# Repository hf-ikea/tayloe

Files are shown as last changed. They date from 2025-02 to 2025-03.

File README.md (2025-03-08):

### tayloe downmixer
This is a simple I/Q downmixer intended for use with a soundcard for digitization, with one (very poor) revision created in a weekend, after I discovered the existence of Tayloe detectors online. Created under the influence of music (sumic). Iterations have occured, with the recommended version being the latest commit to this repo. As of writing, however, the design has not been tested in real world (but shall eventually be). The current (and likely forever) design uses a FT232H communicating over I2C to a Si5351A that is then used in a divide-by-four to create the I/Q paired LO, fed into the multiplexer. On the front end is a simple elliptical LPF with a ~30MHz rolloff, and a 1.8V bias circuit. The sample capacitors are of value 0.068uF, which are on the input of an ADA4084 operational amplifier. This is connected through bypass capacitors to the 3.5mm audio jack. For simplicity, a single rail supply is used for the operational amplifier, as the bias on the input should maintain a proper swing.\
"Inspired" by the classic "A Software Defined Radio for the Masses" Series, published in QEX (and available in this repo).\
Hardware is licensed under CERN Open Hardware Licence Version 2 - Strongly Reciprocal (LICENSE.txt)

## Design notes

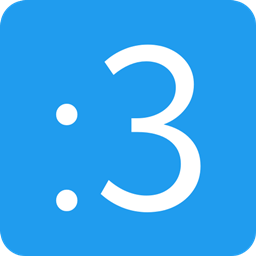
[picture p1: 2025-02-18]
Datasheets/important_data.png

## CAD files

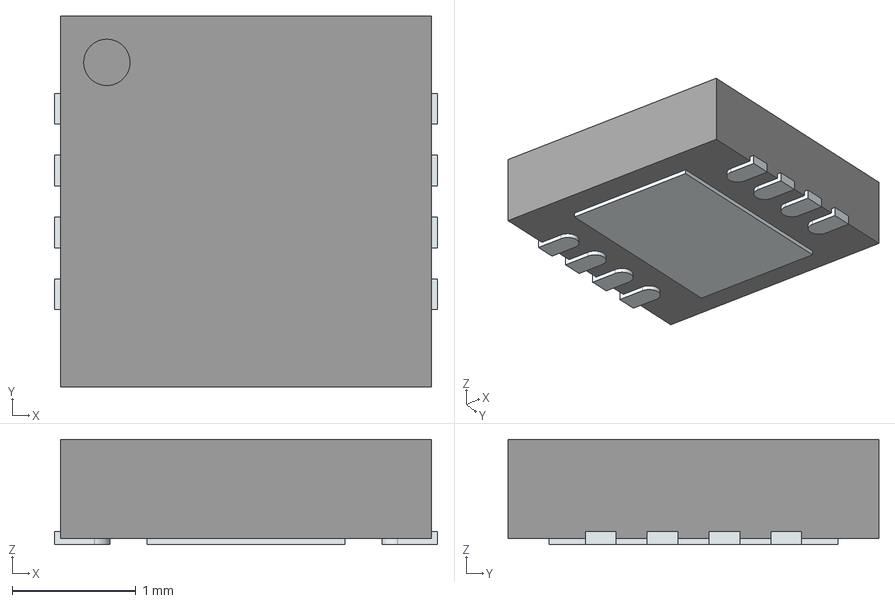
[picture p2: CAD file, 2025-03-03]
3DModels/ADA4084-2ACPZ-R7.stp
3.10 x 3.00 x 0.85 mm
ThermalPin
PinsArrayLR

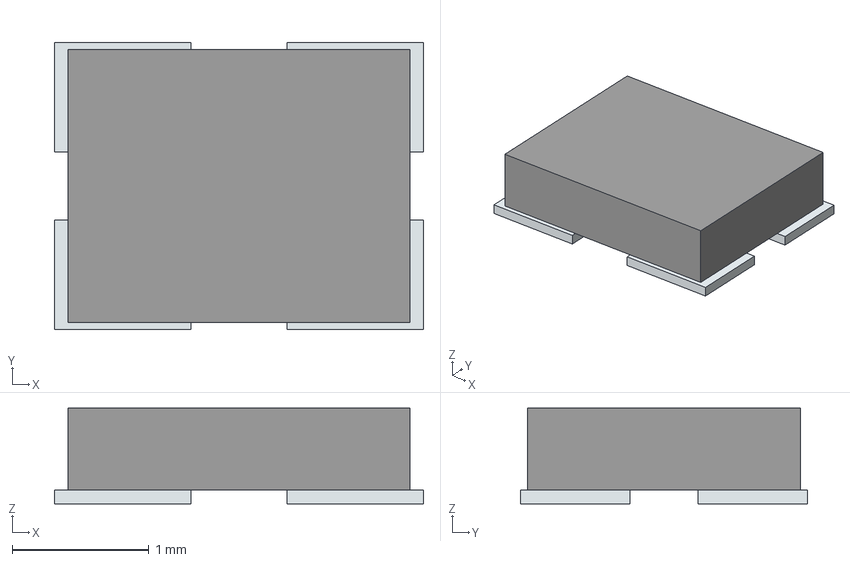
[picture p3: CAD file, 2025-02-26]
3DModels/ECS-120-8-36-CKM-TR3.stp
2.70 x 2.10 x 0.7 mm
Pins

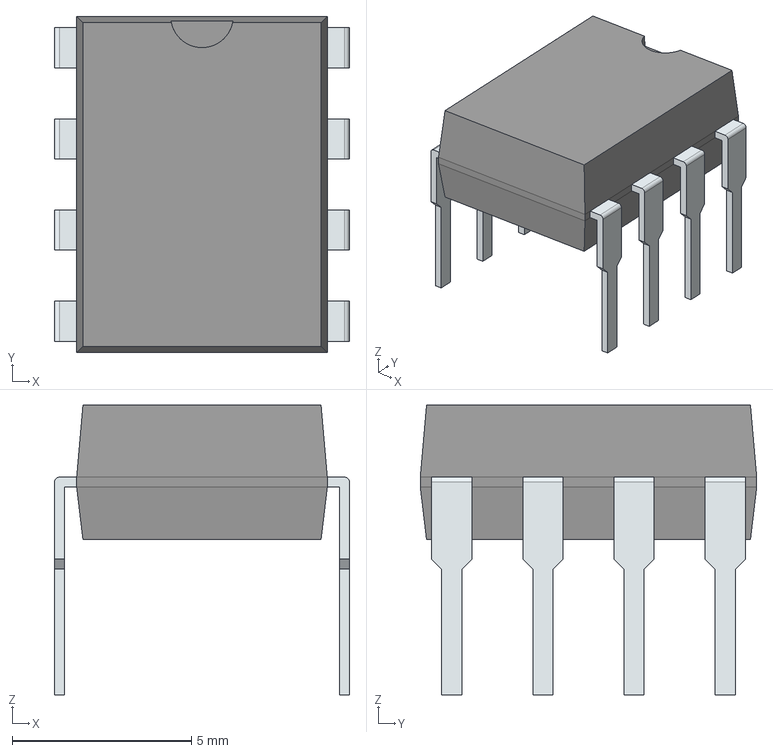
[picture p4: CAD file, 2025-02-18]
3DModels/MAX1044CPA+.stp
8.22 x 9.38 x 8.07 mm
PinsArrayLR

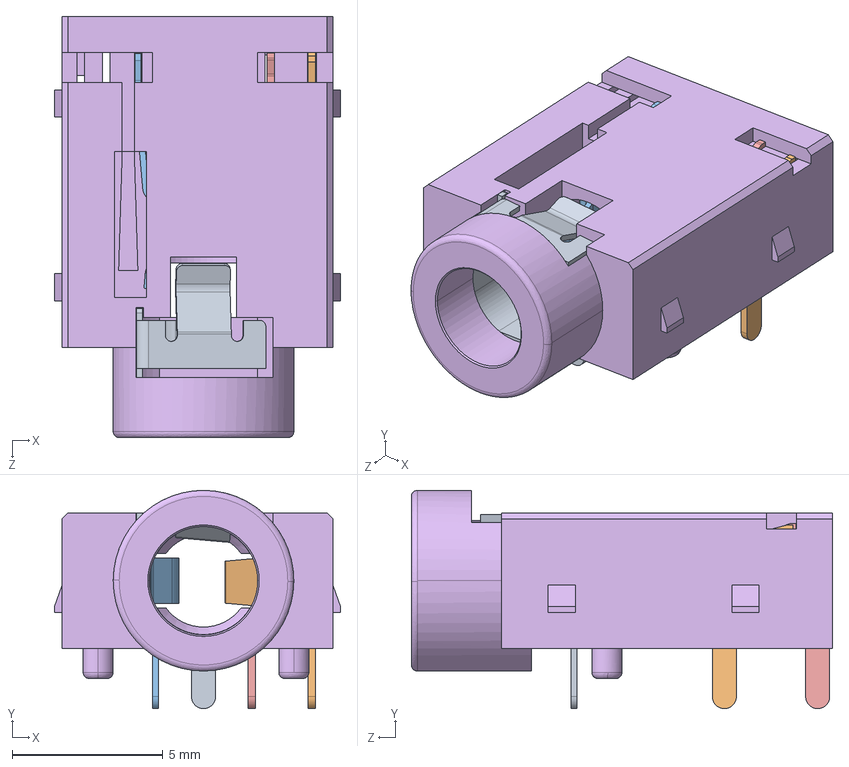
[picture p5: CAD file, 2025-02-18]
3DModels/Same_Sky_SJ3-35063B.step
9.50 x 7.25 x 14.0 mm

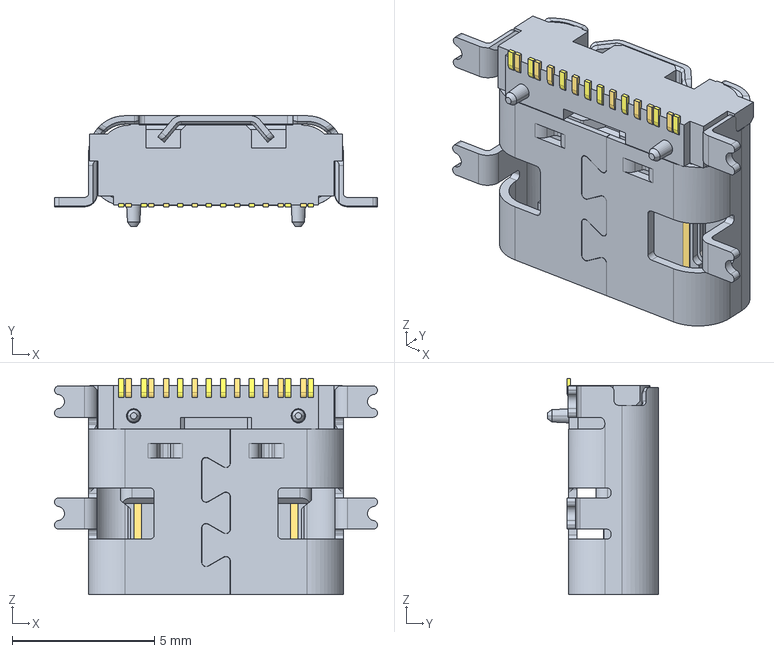
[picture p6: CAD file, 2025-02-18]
3DModels/GSB1C41110SSHR.stp
11.3 x 3.89 x 7.60 mm

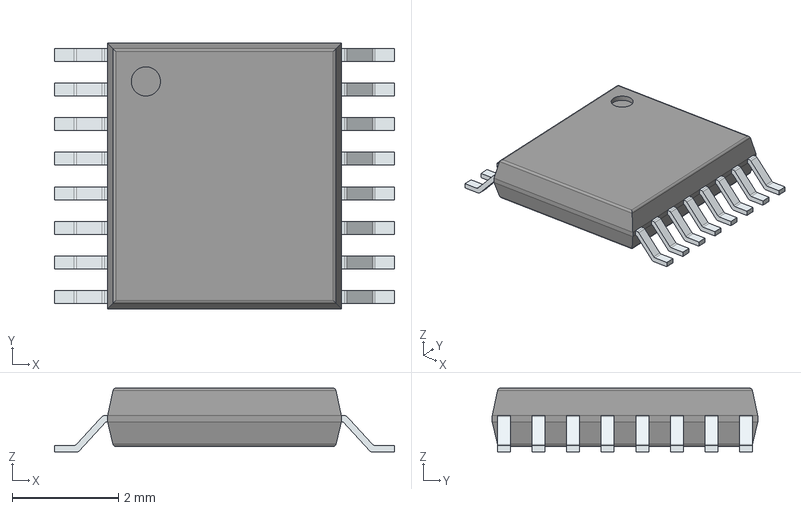
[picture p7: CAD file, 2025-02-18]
3DModels/PI3B3253LEX.stp
6.40 x 5.00 x 1.20 mm
PinsArrayLR

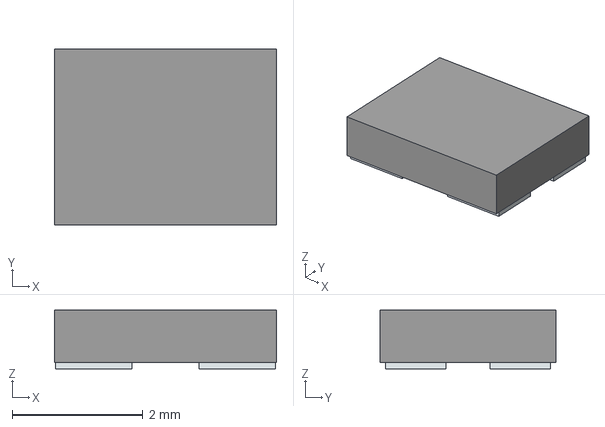
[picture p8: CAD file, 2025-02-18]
3DModels/830105420809.stp
3.40 x 2.70 x 0.9 mm
Pins

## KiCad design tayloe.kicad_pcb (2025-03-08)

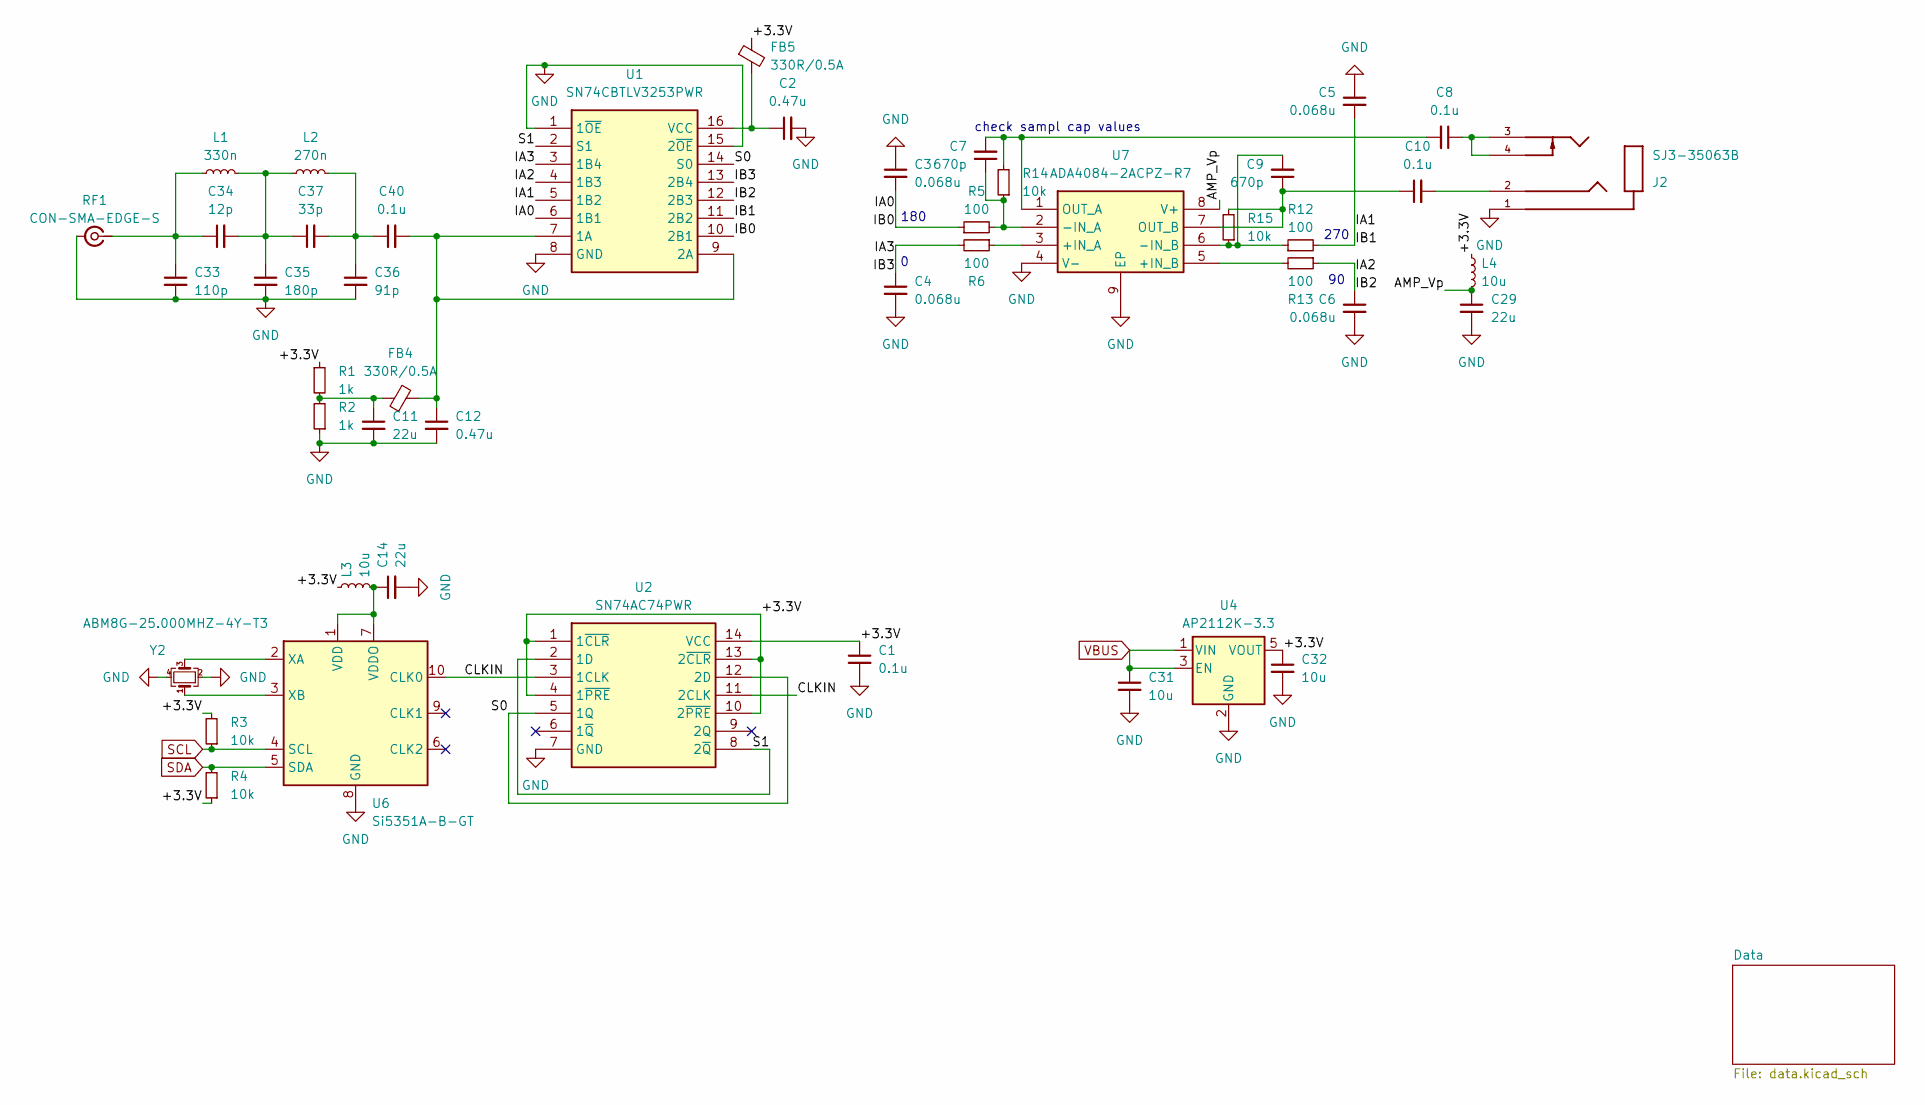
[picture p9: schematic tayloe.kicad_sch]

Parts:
C1, C8, C10, C40: 0.1u; C_0603_1608Metric
C2, C12: 0.47u; C_0603_1608Metric
C3, C4, C5, C6: 0.068u; C_0603_1608Metric; Mouser Part 603-CC603JRX7R8BB683
C7, C9: 670p; C_0603_1608Metric; Mouser Part 603-CC603JRX7R8BB683
C11, C14, C29: 22u; C_0603_1608Metric
C31, C32: 10u; C_0603_1608Metric
C33: 110p; C_0603_1608Metric
C34: 12p; C_0603_1608Metric
C35: 180p; C_0603_1608Metric
C36: 91p; C_0603_1608Metric
C37: 33p; C_0603_1608Metric
FB4, FB5: 330R/0.5A; L_0603_1608Metric; Mouser Part 81-BLM18HK331SN1
J2: SJ3-35063B; SAMESKY_SJ3-35063B; PARTREV 1.0
L1: 330n; L_0603_1608Metric
L2: 270n; L_0603_1608Metric
L3, L4: 10u; L_0603_1608Metric
R1, R2: 1k; R_0603_1608Metric
R3, R4, R14, R15: 10k; R_0603_1608Metric
R5, R6, R12, R13: 100; R_0603_1608Metric
RF1: CON-SMA-EDGE-S; SMA_Amphenol_132289_EdgeMount
U1: SN74CBTLV3253PWR; TSSOP-16_4.4x5mm_P0.65mm; Mouser Part 595-SN74CBTLV3253PWR
U2: SN74AC74PWR; TSSOP-14_4.4x5mm_P0.65mm; Mouser Part Number 595-SN74AC74PWR
U4: AP2112K-3.3; SOT-23-5
U6: Si5351A-B-GT; MSOP-10_3x3mm_P0.5mm
U7: ADA4084-2ACPZ-R7; LFCSP-8-1EP_3x3mm_P0.5mm_EP1.6x2.34mm_ThermalVias; Mouser Part 584-ADA4084-2ACPZ-R7
Y2: ABM8G-25.000MHZ-4Y-T3; Crystal_SMD_Abracon_ABM8G-4Pin_3.2x2.5mm

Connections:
/+3.3V: C1.1, C32.1, FB5.1, L3.1, L4.1, R1.1, R3.2, R4.1, U2.1 (1~CLR), U2.4 (1~PRE), U2.10 (2~PRE), U2.13 (2~CLR), U2.14 (VCC), U4.5 (VOUT)
/AMP_Vp: C29.1, L4.2, U7.8 (V+)
/CLKIN: U2.3 (1CLK), U2.11 (2CLK), U6.10 (CLK0)
/IA0: C3.2, R5.1, U1.6 (1B1), U1.10 (2B1)
/IA1: C5.2, R12.2, U1.5 (1B2), U1.11 (2B2)
/IA2: C6.1, R13.1, U1.4 (1B3), U1.12 (2B3)
/IA3: C4.1, R6.2, U1.3 (1B4), U1.13 (2B4)
/S0: U1.14 (S0), U2.5 (1Q), U2.12 (2D)
/S1: U1.2 (S1), U2.2 (1D), U2.8 (2~Q)
GND: C1.2, C2.2, C3.1, C4.2, C5.1, C6.2, C11.2, C12.2, C14.2, C29.2, C31.2, C32.2, C33.2, C35.2, C36.2, J2.1, R2.1, RF1.2 (Ext), U1.1 (1~OE), U1.8 (GND), U1.15 (2~OE), U2.7 (GND), U4.2 (GND), U6.8 (GND), U7.4 (V-), U7.9 (EP), Y2.2, Y2.4; also elsewhere on the board
unnamed: C8.1, J2.3, J2.4
unnamed: C10.2, J2.2
unnamed: C11.1, FB4.1, R1.2, R2.2
unnamed: C34.2, C35.1, C37.1, L1.2, L2.1
unnamed: C36.1, C37.2, C40.1, L2.2
unnamed: C33.1, C34.1, L1.1, RF1.1 (In)
unnamed: C12.1, C40.2, FB4.2, U1.7 (1A), U1.9 (2A)
unnamed: C2.1, FB5.2, U1.16 (VCC)
unnamed: C14.1, L3.2, U6.1 (VDD), U6.7 (VDDO)
unnamed: U6.2 (XA), Y2.3
unnamed: U6.3 (XB), Y2.1
unnamed: R6.1, U7.3 (+IN_A)
unnamed: R13.2, U7.5 (+IN_B)
unnamed: C7.1, R5.2, R14.1, U7.2 (-IN_A)
unnamed: C9.2, R12.1, R15.1, U7.6 (-IN_B)
unnamed: C7.2, C8.2, R14.2, U7.1 (OUT_A)
unnamed: C9.1, C10.1, R15.2, U7.7 (OUT_B)
SCL: R3.1, U6.4 (SCL); also elsewhere on the board
SDA: R4.2, U6.5 (SDA); also elsewhere on the board
VBUS: C31.1, U4.1 (VIN), U4.3 (EN); also elsewhere on the board

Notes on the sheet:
check sampl cap values
270
180

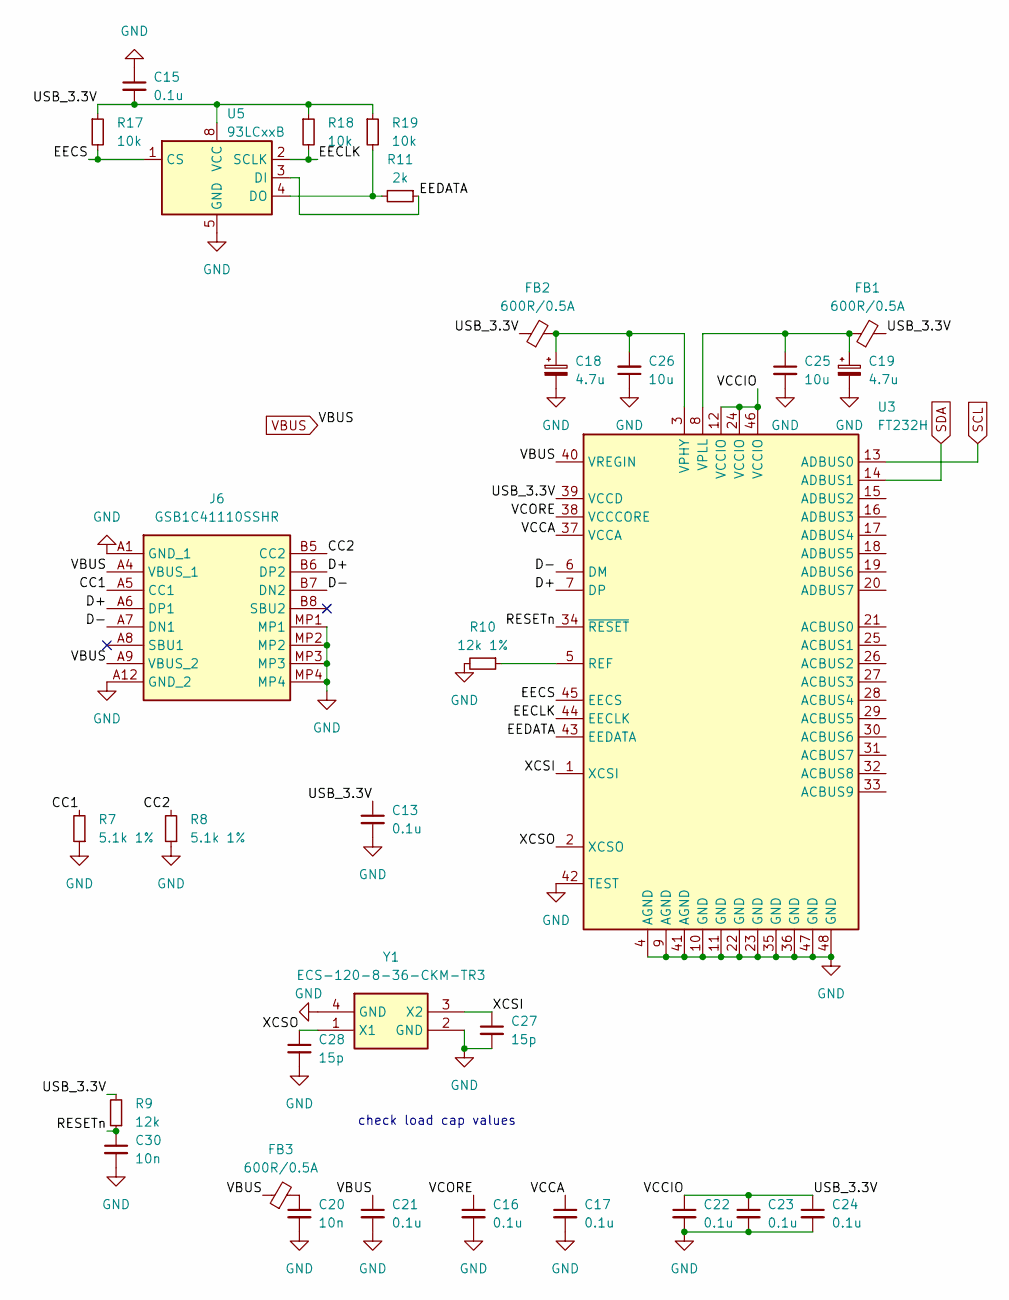
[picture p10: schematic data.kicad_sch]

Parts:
C13, C15, C16, C17, C21, C22, C23, C24: 0.1u; C_0603_1608Metric
C18, C19: 4.7u; CP_Elec_5x5.3
C20, C30: 10n; C_0603_1608Metric
C25, C26: 10u; C_0603_1608Metric
C27, C28: 15p; C_0603_1608Metric
FB1, FB2, FB3: 600R/0.5A; L_0603_1608Metric; Mouser Part 81-BLM18HK601SN1D
J6: GSB1C41110SSHR; Manufacturer_Part_Number GSB1C41110SSHR
R7, R8: 5.1k 1%; R_0603_1608Metric
R9: 12k; R_0603_1608Metric
R10: 12k 1%; R_0603_1608Metric
R11: 2k; R_0603_1608Metric
R17, R18, R19: 10k; R_0603_1608Metric
U3: FT232H; LQFP-48_7x7mm_P0.5mm
U5: 93LCxxB; SOIC-8_3.9x4.9mm_P1.27mm
Y1: ECS-120-8-36-CKM-TR3; ECS120836CKMTR3; Mouser Part 520-120-8-36-CKM-TR3

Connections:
/Data/CC1: J6.A5 (CC1), R7.2
/Data/CC2: J6.B5 (CC2), R8.2
/Data/D+: J6.A6 (DP1), J6.B6 (DP2), U3.7 (DP)
/Data/D-: J6.A7 (DN1), J6.B7 (DN2), U3.6 (DM)
/Data/EECLK: R18.2, U3.44 (EECLK), U5.2 (SCLK)
/Data/EECS: R17.2, U3.45 (EECS), U5.1 (CS)
/Data/EEDATA: R11.1, U3.43 (EEDATA), U5.3 (DI)
/Data/RESETn: C30.1, R9.1, U3.34 (~RESET)
/Data/USB_3.3V: C13.1, C15.2, C22.1, C23.1, C24.1, FB1.2, FB2.1, R9.2, R17.1, R18.1, R19.1, U3.12 (VCCIO), U3.24 (VCCIO), U3.39 (VCCD), U3.46 (VCCIO), U5.8 (VCC)
/Data/VCCA: C17.1, U3.37 (VCCA)
/Data/VCORE: C16.1, U3.38 (VCCCORE)
/Data/XCSI: C27.1, U3.1 (XCSI), Y1.3 (X2)
/Data/XCSO: C28.1, U3.2 (XCSO), Y1.1 (X1)
GND: C13.2, C15.1, C16.2, C17.2, C18.2, C19.2, C20.2, C21.2, C22.2, C23.2, C24.2, C25.2, C26.1, C27.2, C28.2, C30.2, J6.A1 (GND_1), J6.A12 (GND_2), J6.MP1, J6.MP2, J6.MP3, J6.MP4, R7.1, R8.1, R10.2, U3.4 (AGND), U3.9 (AGND), U3.10 (GND), U3.11 (GND), U3.22 (GND), U3.23 (GND), U3.35 (GND), U3.36 (GND), U3.41 (AGND), U3.42 (TEST), U3.47 (GND), U3.48 (GND), U5.5 (GND), Y1.2 (GND), Y1.4 (GND); also elsewhere on the board
unnamed: C20.1, FB3.2
unnamed: R10.1, U3.5 (REF)
unnamed: C18.1, C26.2, FB2.2, U3.3 (VPHY)
unnamed: C19.1, C25.1, FB1.1, U3.8 (VPLL)
unnamed: R11.2, R19.2, U5.4 (DO)
SCL: U3.13 (ADBUS0); also elsewhere on the board
SDA: U3.14 (ADBUS1); also elsewhere on the board
VBUS: C21.1, FB3.1, J6.A4 (VBUS_1), J6.A9 (VBUS_2), U3.40 (VREGIN); also elsewhere on the board

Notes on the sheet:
check load cap values

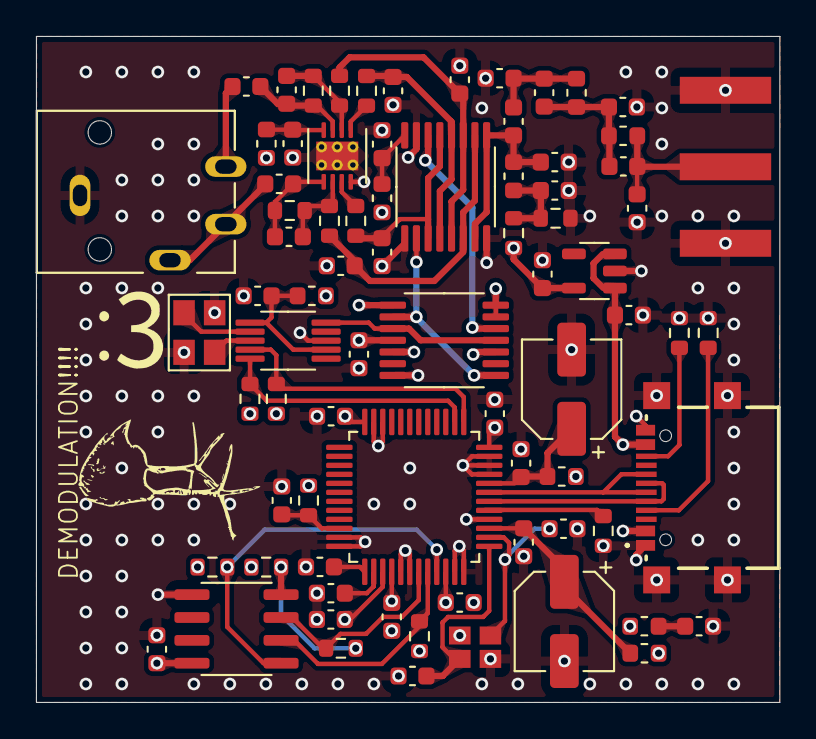
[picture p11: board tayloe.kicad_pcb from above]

Board: 4 copper layers, 41.3 x 37.0 mm, 78 parts (0 on the bottom side), 48 nets.

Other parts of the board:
G**: bird

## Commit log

2025-02-18 first version
    [830105420809.stp, GSB1C41110SSHR.stp, MAX1044CPA+.stp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]
2025-02-26 rev 2
    [ECS-120-8-36-CKM-TR3.stp, tayloe.kicad_pcb, tayloe.kicad_sch]
2025-03-03 rev 3
    [ADA4084-2ACPZ-R7.stp, data.kicad_sch, tayloe.kicad_pcb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]
2025-03-04 remove file
    [frontend.kicad_sch, tayloe.kicad_pcb]
2025-03-08 rev 3.1
    [tayloe.kicad_pcb, tayloe.kicad_sch]
2025-03-08 i forgor via stiching (rev 3.2) (for real this time)
    [tayloe.kicad_pcb]
